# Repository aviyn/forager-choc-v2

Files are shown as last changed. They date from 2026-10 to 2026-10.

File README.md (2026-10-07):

Forager keyboard in white

# Forager

Forager is a Voyager-inspired 34-key low-profile wireless split keyboard powered by ZMK.

> why does the large Voyager not simply eat the small Forager?

## Choc v2 / 19 mm fork

This fork of [carrefinho/forager](https://github.com/carrefinho/forager) reworks the PCB for **Choc v2 hotswap switches at 19 × 19 mm spacing** (each half is about 8 mm wider and 6 mm taller) and adds, on each half:

- a power switch (Alps SSSS811101)
- an optional reset button (Panasonic EVQ-PUC02K)
- three SK6812MINI-E status LEDs behind a P-FET power switch

The schematic and board are done. The case, the LED firmware, the Gerbers and the build guide have not been updated yet and still describe the original design. See [the full list of changes](/docs/changes.md).

## Design

- Condensed [ZSA Voyager](https://www.zsa.io/voyager) layout without outer pinkie column and number row
- Hot-swap Kailh Choc V1 switches in Choc (18x17mm) spacing with Voyager-esque switch puller grooves

Switch-plate cutouts

- Wireless only with Seeed XIAO nRF52840 running ZMK firmware
- Magnetic tenting legs inspired by Voyager and [Unicorne](https://www.boardsource.xyz/products/unicorne)

Forager keyboard with magnetic tenting legs attached

- Compact silhouette without the usual blank space occupied by controller
- Fully enclosed with 3D-printed two-piece case
- Minimal BOM by utilizing XIAO nRF52840's onboard RGB LED and reset button

Forager keyboard with LED indicator lit up in blue alongside reset button on the bottom

## Build Guide and Parts List

[Find the build guide here.](/docs/build-guide.md)

## Firmware

[Find the ZMK module here.](https://github.com/carrefinho/forager-zmk-module)

## Credits

- [ZSA Voyager](https://www.zsa.io/voyager): overall layout & aesthetics
- [GEIGEIGEIST/TOTEM](https://github.com/GEIGEIGEIST/TOTEM): XIAO PCB footprint and general placement
- [ebastler/marbastlib](https://github.com/ebastler/marbastlib): symbols and PCB footprints
- [caksoylar/zmk-rgbled-widget](https://github.com/caksoylar/zmk-rgbled-widget): RGB LED functionality

## Gallery

Forager keyboard in white
Forager keyboard in black and white
Forager keyboard with detached tenting leg
Forager keyboard in black

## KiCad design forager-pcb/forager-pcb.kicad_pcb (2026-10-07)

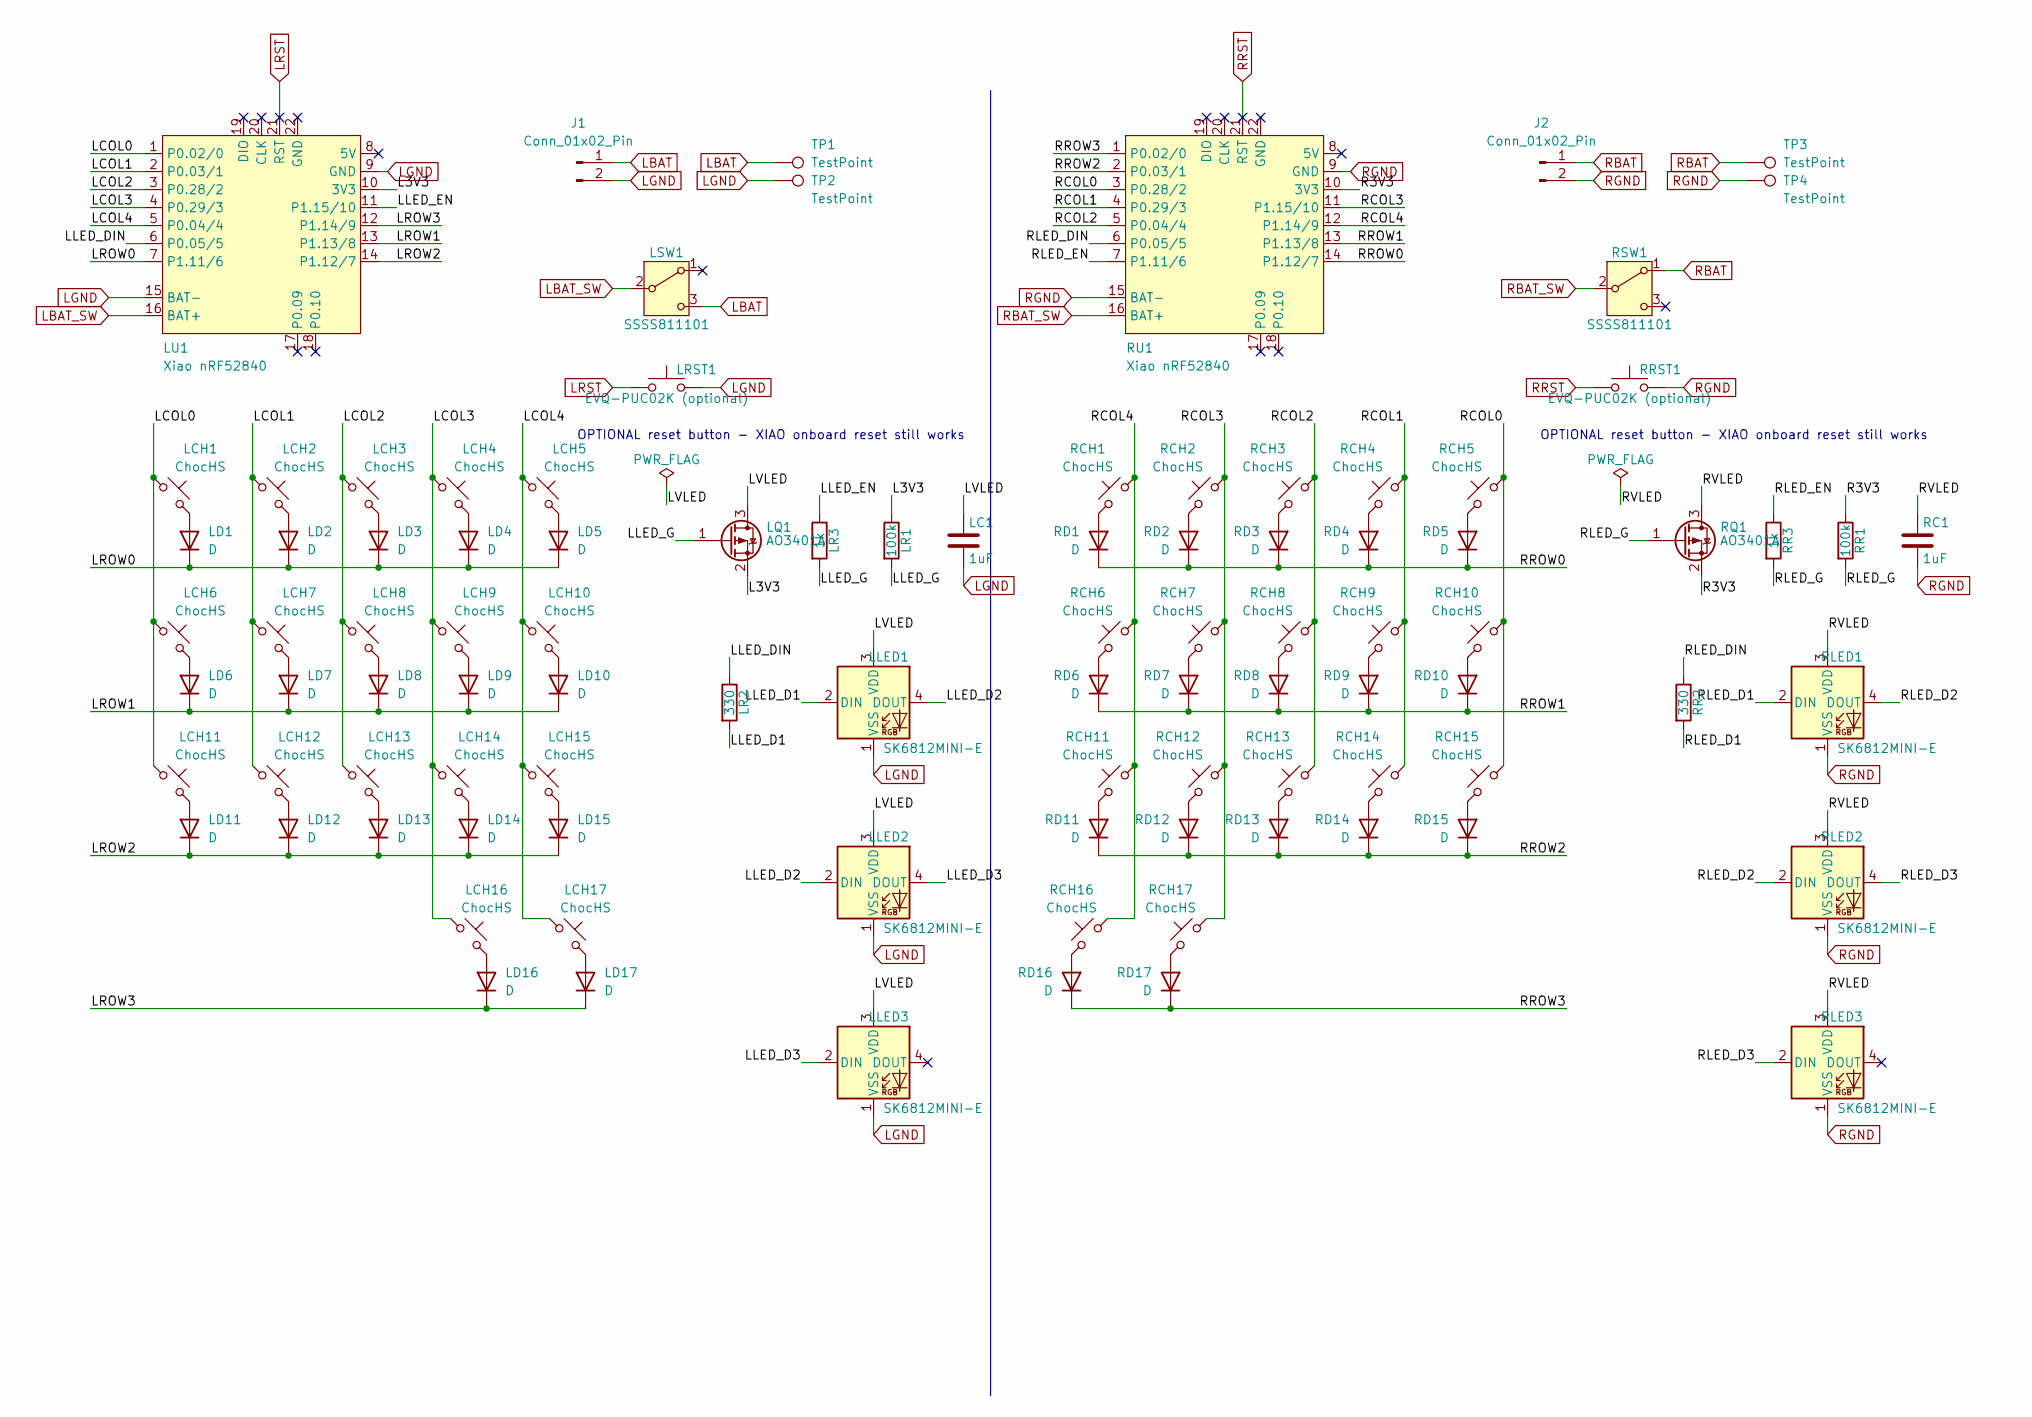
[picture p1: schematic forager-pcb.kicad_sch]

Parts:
J1, J2: Conn_01x02_Pin; JST_ACH_BM02B-ACHSS-GAN-ETF_1x02-1MP_P1.20mm_Vertical
LC1: 1uF; C_1206_3216Metric_Pad1.33x1.80mm_HandSolder; LCSC C1848
LCH1, LCH2, LCH3, LCH4, LCH5, LCH6, LCH7, LCH8, LCH9, LCH10, LCH11, LCH12, LCH13, LCH14, LCH15, LCH16, LCH17: ChocHS; SW_choc_v2_HS_CPG135001S30_1u_nopost
LD1, LD2, LD3, LD4, LD5, LD6, LD7, LD8, LD9, LD10, LD11, LD12, LD13, LD14, LD15, LD16, LD17: D; D_SOD-123
LLED1, LLED2, LLED3: SK6812MINI-E; LED_SK6812MINI-E_3.2x2.8mm_P1.5mm_ReverseMount; LCSC C5149201
LQ1: AO3401A; SOT-23; LCSC C347476
LR1: 100k; R_1206_3216Metric_Pad1.30x1.75mm_HandSolder; LCSC C17900
LR2: 330; R_1206_3216Metric_Pad1.30x1.75mm_HandSolder; LCSC C25374
LR3: 1k; R_1206_3216Metric_Pad1.30x1.75mm_HandSolder; LCSC C4410
LRST1: EVQ-PUC02K (optional); SW_Panasonic_EVQPUC02K
LSW1: SSSS811101; SW_SPDT_Alps_SSSS811101
LU1: Xiao nRF52840; xiao-ble-smd-cutout
RC1: 1uF; C_1206_3216Metric_Pad1.33x1.80mm_HandSolder; LCSC C1848
RCH1, RCH2, RCH3, RCH4, RCH5, RCH6, RCH7, RCH8, RCH9, RCH10, RCH11, RCH12, RCH13, RCH14, RCH15, RCH16, RCH17: ChocHS; SW_choc_v2_HS_CPG135001S30_1u_nopost
RD1, RD2, RD3, RD4, RD5, RD6, RD7, RD8, RD9, RD10, RD11, RD12, RD13, RD14, RD15, RD16, RD17: D; D_SOD-123
RLED1, RLED2, RLED3: SK6812MINI-E; LED_SK6812MINI-E_3.2x2.8mm_P1.5mm_ReverseMount; LCSC C5149201
RQ1: AO3401A; SOT-23; LCSC C347476
RR1: 100k; R_1206_3216Metric_Pad1.30x1.75mm_HandSolder; LCSC C17900
RR2: 330; R_1206_3216Metric_Pad1.30x1.75mm_HandSolder; LCSC C25374
RR3: 1k; R_1206_3216Metric_Pad1.30x1.75mm_HandSolder; LCSC C4410
RRST1: EVQ-PUC02K (optional); SW_Panasonic_EVQPUC02K
RSW1: SSSS811101; SW_SPDT_Alps_SSSS811101
RU1: Xiao nRF52840; xiao-ble-smd-cutout
TP1, TP2, TP3, TP4: TestPoint; TestPoint_Pad_D2.0mm

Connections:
/L3V3: LQ1.2 (S), LR1.1, LU1.10 (3V3)
/LCOL0: LCH1.1, LCH6.1, LCH11.1, LU1.1 (P0.02/0)
/LCOL1: LCH2.1, LCH7.1, LCH12.1, LU1.2 (P0.03/1)
/LCOL2: LCH3.1, LCH8.1, LCH13.1, LU1.3 (P0.28/2)
/LCOL3: LCH4.1, LCH9.1, LCH14.1, LCH16.1, LU1.4 (P0.29/3)
/LCOL4: LCH5.1, LCH10.1, LCH15.1, LCH17.1, LU1.5 (P0.04/4)
/LLED_D1: LLED1.2 (DIN), LR2.2
/LLED_D2: LLED1.4 (DOUT), LLED2.2 (DIN)
/LLED_D3: LLED2.4 (DOUT), LLED3.2 (DIN)
/LLED_DIN: LR2.1, LU1.6 (P0.05/5)
/LLED_EN: LR3.1, LU1.11 (P1.15/10)
/LLED_G: LQ1.1 (G), LR1.2, LR3.2
/LROW0: LD1.1 (K), LD2.1 (K), LD3.1 (K), LD4.1 (K), LD5.1 (K), LU1.7 (P1.11/6)
/LROW1: LD6.1 (K), LD7.1 (K), LD8.1 (K), LD9.1 (K), LD10.1 (K), LU1.13 (P1.13/8)
/LROW2: LD11.1 (K), LD12.1 (K), LD13.1 (K), LD14.1 (K), LD15.1 (K), LU1.14 (P1.12/7)
/LROW3: LD16.1 (K), LD17.1 (K), LU1.12 (P1.14/9)
/LVLED: LC1.1, LLED1.3 (VDD), LLED2.3 (VDD), LLED3.3 (VDD), LQ1.3 (D)
/R3V3: RQ1.2 (S), RR1.1, RU1.10 (3V3)
/RCOL0: RCH5.1, RCH10.1, RCH15.1, RU1.3 (P0.28/2)
/RCOL1: RCH4.1, RCH9.1, RCH14.1, RU1.4 (P0.29/3)
/RCOL2: RCH3.1, RCH8.1, RCH13.1, RU1.5 (P0.04/4)
/RCOL3: RCH2.1, RCH7.1, RCH12.1, RCH17.1, RU1.11 (P1.15/10)
/RCOL4: RCH1.1, RCH6.1, RCH11.1, RCH16.1, RU1.12 (P1.14/9)
/RLED_D1: RLED1.2 (DIN), RR2.2
/RLED_D2: RLED1.4 (DOUT), RLED2.2 (DIN)
/RLED_D3: RLED2.4 (DOUT), RLED3.2 (DIN)
/RLED_DIN: RR2.1, RU1.6 (P0.05/5)
/RLED_EN: RR3.1, RU1.7 (P1.11/6)
/RLED_G: RQ1.1 (G), RR1.2, RR3.2
/RROW0: RD1.1 (K), RD2.1 (K), RD3.1 (K), RD4.1 (K), RD5.1 (K), RU1.14 (P1.12/7)
/RROW1: RD6.1 (K), RD7.1 (K), RD8.1 (K), RD9.1 (K), RD10.1 (K), RU1.13 (P1.13/8)
/RROW2: RD11.1 (K), RD12.1 (K), RD13.1 (K), RD14.1 (K), RD15.1 (K), RU1.2 (P0.03/1)
/RROW3: RD16.1 (K), RD17.1 (K), RU1.1 (P0.02/0)
/RVLED: RC1.1, RLED1.3 (VDD), RLED2.3 (VDD), RLED3.3 (VDD), RQ1.3 (D)
LBAT: J1.1, LSW1.3 (C), TP1.1 (1_1)
LBAT_SW: LSW1.2 (B), LU1.16 (BAT+)
LGND: J1.2, LC1.2, LLED1.1 (VSS), LLED2.1 (VSS), LLED3.1 (VSS), LRST1.2, LU1.9 (GND), LU1.15 (BAT-), TP2.1 (1_1)
LRST: LRST1.1, LU1.21 (RST)
unnamed: LCH1.2, LD1.2 (A)
unnamed: LCH2.2, LD2.2 (A)
unnamed: LCH3.2, LD3.2 (A)
unnamed: LCH4.2, LD4.2 (A)
unnamed: LCH5.2, LD5.2 (A)
unnamed: LCH6.2, LD6.2 (A)
unnamed: LCH7.2, LD7.2 (A)
unnamed: LCH8.2, LD8.2 (A)
unnamed: LCH9.2, LD9.2 (A)
unnamed: LCH10.2, LD10.2 (A)
unnamed: LCH11.2, LD11.2 (A)
unnamed: LCH12.2, LD12.2 (A)
unnamed: LCH13.2, LD13.2 (A)
unnamed: LCH14.2, LD14.2 (A)
unnamed: LCH15.2, LD15.2 (A)
unnamed: LCH16.2, LD16.2 (A)
unnamed: LCH17.2, LD17.2 (A)
unnamed: RCH1.2, RD1.2 (A)
unnamed: RCH2.2, RD2.2 (A)
unnamed: RCH3.2, RD3.2 (A)
unnamed: RCH4.2, RD4.2 (A)
unnamed: RCH5.2, RD5.2 (A)
unnamed: RCH6.2, RD6.2 (A)
unnamed: RCH7.2, RD7.2 (A)
unnamed: RCH8.2, RD8.2 (A)
unnamed: RCH9.2, RD9.2 (A)
unnamed: RCH10.2, RD10.2 (A)
unnamed: RCH11.2, RD11.2 (A)
unnamed: RCH12.2, RD12.2 (A)
unnamed: RCH13.2, RD13.2 (A)
unnamed: RCH14.2, RD14.2 (A)
unnamed: RCH15.2, RD15.2 (A)
unnamed: RCH16.2, RD16.2 (A)
unnamed: RCH17.2, RD17.2 (A)
RBAT: J2.1, RSW1.1 (A), TP3.1 (1_1)
RBAT_SW: RSW1.2 (B), RU1.16 (BAT+)
RGND: J2.2, RC1.2, RLED1.1 (VSS), RLED2.1 (VSS), RLED3.1 (VSS), RRST1.2, RU1.9 (GND), RU1.15 (BAT-), TP4.1 (1_1)
RRST: RRST1.1, RU1.21 (RST)

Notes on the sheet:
OPTIONAL reset button - XIAO onboard reset still works

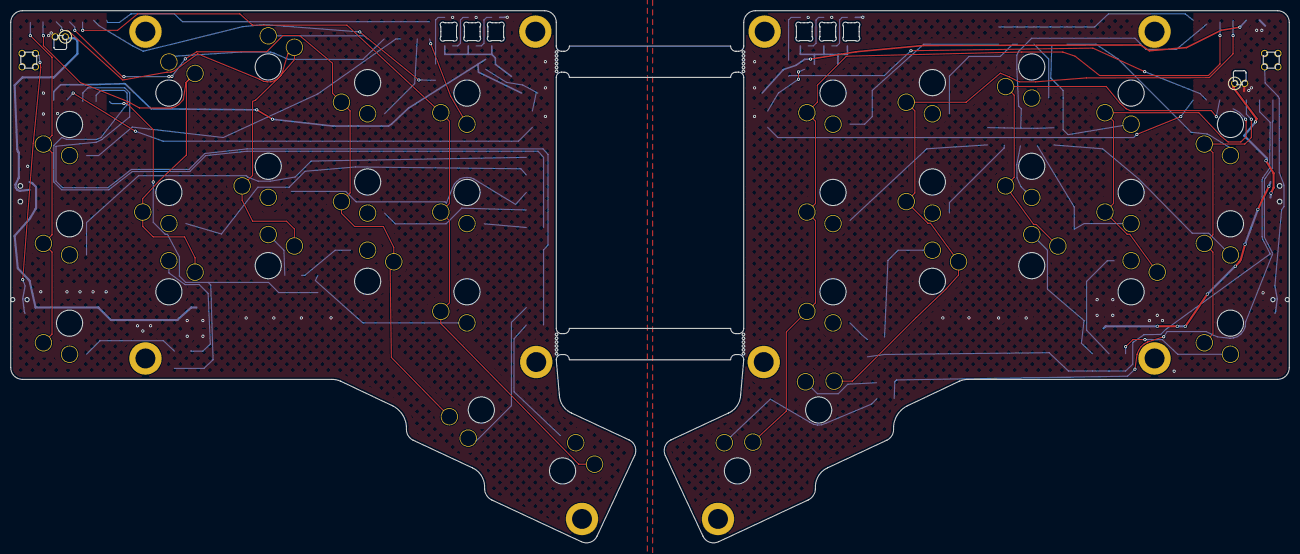
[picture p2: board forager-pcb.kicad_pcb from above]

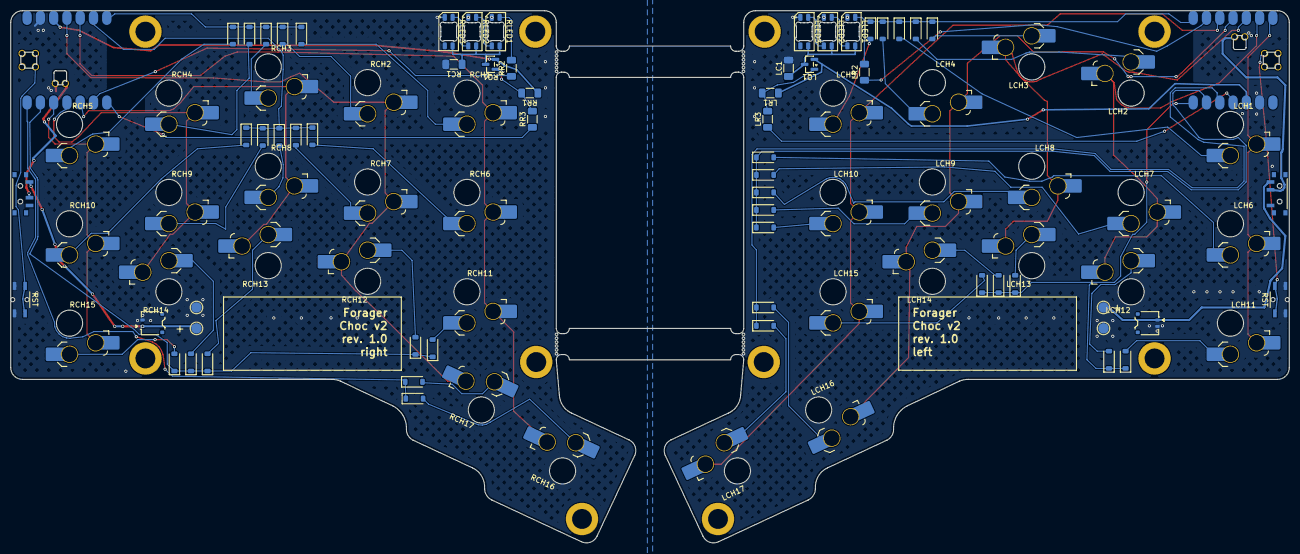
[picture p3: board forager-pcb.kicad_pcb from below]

Board: 2 copper layers, 244.5 x 101.8 mm, 96 parts (96 on the bottom side), 76 nets.

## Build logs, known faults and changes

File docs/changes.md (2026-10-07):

# Forager Choc v2 / 19 mm: Changes

This fork modifies the [original Forager](https://github.com/carrefinho/forager) PCB. It moves the board from **Choc v1 hotswap at 18 × 17 mm** to **Choc v2 hotswap at 19 × 19 mm**, and adds a power switch, an optional reset button and status LEDs to each half.

> **Status:** the schematic and PCB are complete and routed (DRC: 0 errors, 0 unconnected items; ERC: no new errors compared with the original). The [build guide](build-guide.md), the [case](../case/) and the Gerbers still describe the **original** design. See [Not done yet](#not-done-yet).

## Summary

| Area | Original | This fork |
| ---- | --- | --- |
| Switches | Choc v1 hotswap | Choc v2 hotswap (post-less footprint) |
| Key spacing | 18 × 17 mm | 19 × 19 mm |
| Board size (per half) | - | about 8 mm wider and 6 mm taller |
| Power switch | none | Alps SSSS811101 on each half |
| Reset button | XIAO onboard button only | optional Panasonic EVQ-PUC02K on each half |
| Status LEDs | XIAO onboard RGB LED | 3 × SK6812MINI-E per half, behind a P-FET power switch |

## What changed

### 19 × 19 mm grid

- Every key was moved to a 19 × 19 mm pitch. The stagger is kept; only the pitch changed.
- The home row and the inner column stay where they were. Each column moves outward by 1 mm per column, and the top and bottom rows move 2 mm away from the home row.
- Thumb keys keep their 25° angle at the 19 mm pitch, with 1 mm of extra drop to keep the keycap gap.
- Traces, vias, outline, snap-off tabs and GND pours were remapped to match, and the XIAO antenna keepouts moved with the XIAOs.

### Choc v2 hotswap footprint

- Footprint: `forager:SW_choc_v2_HS_CPG135001S30_1u_nopost`, in [`forager-pcb/lib/forager.pretty/`](../forager-pcb/lib/forager.pretty/).
- It is derived from marbastlib's `SW_choc_v2_HS_CPG135001S30_1u`, which is vendored with its license in [`forager-pcb/lib/marbastlib-xp-choc.pretty/`](../forager-pcb/lib/marbastlib-xp-choc.pretty/).
- The centre hole is **5.0 mm**. It was not widened, to avoid switch rattle.
- The footprint has **no side positioning post**, because the post collided with XIAO pins, J1, diodes, test points and a standoff. If your switches have the post, clip it off.
- The socket is still the CPG135001S30, with its pads in the same positions as the v1 footprint.
- Choc v2 has a 5.0 mm centre stem (v1 has 3.4 mm) but the same socket pin positions. Kailh's "Pro" Choc switches (Red, Pink, Light Blue Pro) are still **v1**.

### XIAO

- Both XIAOs moved 0.3 mm toward the top edge so the outer top key's 5 mm hole clears XIAO pins 4 and 11.
- A ground tie trace now connects pad 15 (front) and pad 9 (back) to the GND fill.

### Power switch (both halves)

- Part: **Alps SSSS811101**. The land pattern was checked against the Alps drawing (terminals at -2.25, +0.75 and +2.25 mm, with ② as the common).
- Footprint: `forager:SW_SPDT_Alps_SSSS811101`, on the back side at the outer edge below the XIAO. The slider overhangs the board edge by about 1 mm.
- Circuit: battery (J1/J2 and test pad) → switch → XIAO BAT+. The new nets are `LBAT_SW` and `RBAT_SW`.
- **Slider up = on** on both halves. The down-end pin is not connected.
- Routing changes: the left battery trace was rerouted; on the right, `RROW2` and `RROW3` jog about 1.5 mm inward and the battery traces hop to the front copper. Three GND stitching vias under the left switch were removed.

### Reset button (optional, both halves)

- Part: **Panasonic EVQ-PUC02K**, side-push with bosses, per Panasonic drawing ES103 No. 2.
- Footprint: `forager:SW_Panasonic_EVQPUC02K`, on the back side at the outer edge **below the power switch**, with the push plate about 1 mm past the edge.
- Circuit: XIAO RST (pad 21) to GND, on the new nets `LRST` and `RRST`.
- It is optional. The XIAO's onboard reset button still works if you leave it off. Each button has an "RST" silkscreen label.

### Status LEDs (both halves)

- 3 × **SK6812MINI-E** per half, reverse-mounted on the top inner edge and shining up through board cutouts. LED pitch is 4.5 mm.
- Data: XIAO **P0.05** → 330 Ω → LED1 → LED2 → LED3. LED3's DOUT is not connected.
- Power: an **AO3401A** P-FET switches the LED supply from the XIAO's 3V3 pin, so the LEDs draw nothing when off. The enable line is active low, with a 1k series resistor and a 100k pull-up, plus a 1 µF capacitor on the switched rail.
- **This uses every remaining free GPIO on both XIAOs.**

| Signal | Left half | Right half |
| --- | --- | --- |
| LED data (DIN) | P0.05 (pad 6) | P0.05 (pad 6) |
| LED enable (active low) | P1.15 (pad 11) | P1.11 (pad 7) |
| LED supply | 3V3 (pad 10) | 3V3 (pad 10) |

- **LED order:** the chain runs left to right (+x) on both halves. On the left half LED1 is the outer LED (nearest the XIAO); on the right half LED1 is the inner LED. Firmware has to map the indices accordingly.
- **Light pipes:** the case needs one 1.75 mm hole centred on each LED, at the six (x, -47.75) positions. Check these against the top-case key openings.
- **Soldering:** four LED ground pads use a via in the pad. Some solder wicks into the open hole, so use a little more solder, or order filled or capped vias.
- Per-LED 100 nF decoupling capacitors were left out.

## Added parts (per half)

| Part | Value / part number | Ref (L / R) | Count | LCSC |
| ---- | --- | --- | ----- | ---- |
| Power switch | Alps SSSS811101 | LSW1 / RSW1 | 1 | - |
| Reset button (optional) | Panasonic EVQ-PUC02K | - | 1 | - |
| RGB LED | SK6812MINI-E | LLED1-3 / RLED1-3 | 3 | C5149201 |
| P-FET | AO3401A (SOT-23) | LQ1 / RQ1 | 1 | C347476 |
| Resistor, 1206 | 100k | LR1 / RR1 | 1 | C17900 |
| Resistor, 1206 | 330 Ω | LR2 / RR2 | 1 | C25374 |
| Resistor, 1206 | 1k | LR3 / RR3 | 1 | C4410 |
| Capacitor, 1206 | 1 µF | LC1 / RC1 | 1 | C1848 |

Multiply by two for a full keyboard. The switches themselves are not in the build guide's parts list, but they now need to be **Choc v2 switches** (for example Kailh Black Cloud) with **MX-compatible keycaps**. The hotswap socket (CPG135001S30) is unchanged.

## Not done yet

- **Case:** the files in [`case/`](../case/) are still for 18 × 17 mm and Choc v1. They need the 19 × 19 outline, Choc v2 plate cutouts (MX-style 14 mm; rethink the puller grooves), moved standoffs, outer-wall slots for the power slider and reset button, six light-pipe holes, and moved XIAO and USB-C openings.
- **Firmware:** the key matrix is unchanged. The LED support still has to be written (a ZMK module with a WS2812 driver on P0.05 via SPI, and the active-low enable GPIO).
- **Fab outputs:** `forager-pcb/GERBER-forager-pcb.zip` is **stale** and still the original board. Regenerate Gerbers, drill, BOM and position files, and check that the LED cutouts appear in Edge.Cuts and that the plotted silkscreen font (Geist) is right.
- **Build guide:** still describes the original build, including the case steps and the onboard-LED light guides.

## Known issues and review items

- Silkscreen: the LED reference labels overlap the LED cutouts. Optionally add an "ON ▲" mark next to the power switches.
- Worth a visual check in KiCad: the `RBAT_SW` reroute on the right half, the `RROW2`/`RROW3` jog around the right power switch, `R3V3` running between the right resistor's pads, and the two-via hop on `RLED_G`.
- Remaining DRC warnings (about 40) are inherited or cosmetic: missing library paths, `lib_footprint_mismatch`, silkscreen overlaps, and schematic-parity items for board-only parts (standoff nuts, snap-off tabs, J1/J2 mounting pads). `copper_edge_clearance` is ignored in this project, as in the original.
- Several footprints (standoffs, switch holes, the XIAO) have no courtyard, so fit checks have to use pads and holes.

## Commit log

2026-10-06 Re-grid Forager to 19x19 mm pitch; add Choc v2 hotswap footprint lib
    Keys moved to 19x19 pitch (column stagger and thumb angle kept), traces,
    vias, outline, zones remapped. Schematic switch footprints set to
    marbastlib-xp-choc:SW_choc_v2_HS_CPG135001S30_1u.
    [forager-pcb.kicad_pcb, forager-pcb.kicad_sch]
2026-10-06 Use post-less Choc v2 hotswap footprint (5.0mm centre stem) for all switches
    New project lib forager.pretty with SW_choc_v2_HS_CPG135001S30_1u_nopost,
    derived from marbastlib (side positioning post removed).
    [forager-pcb.kicad_pcb, forager-pcb.kicad_sch]
2026-10-06 Reroute traces around Choc v2 5mm centre holes
    45 trace chains locally rerouted (6 hop layers via 2 vias each), 3 GND
    vias nudged, near-miss clearances fixed. DRC: 0 unconnected; remaining
    errors are 2 XIAO pin-to-centre-hole and 5 XIAO GND thermal spokes.
    [forager-pcb.kicad_pcb]
2026-10-06 Move XIAOs 0.3mm up for centre-hole clearance; tie XIAO GND pads to fill
    DRC: 0 errors, 0 unconnected.
    [forager-pcb.kicad_pcb]
2026-10-06 Add 3D models: Choc switch, hotswap socket, MX keycap, XIAO (vendored)
    Choc v1 switch model used as visual stand-in for Choc v2 (same housing).
    [forager-pcb.kicad_pcb]
2026-10-06 Fix XIAO 3D model orientation (USB-C out the side edge)
    [forager-pcb.kicad_pcb]
2026-10-06 Silkscreen: Forager / Choc v2 / rev. 1.0
    [forager-pcb.kicad_pcb]
2026-10-06 Add Alps SSSS811101 power switches (up = on) on outer edges
    - New footprint forager:SW_SPDT_Alps_SSSS811101 (Alps land pattern) + simple 3D model
    - Schematic: LSW1/RSW1 in series with battery; XIAO BAT+ on new LBAT_SW/RBAT_SW nets
    (POWER class). Battery on the top pin of each switch, so slider up = on on both halves.
    - PCB: switches on bottom at outer edge below XIAO, slider overhanging edge;
    battery lines rerouted, RROW2/RROW3 moved inward around RSW1, 3 GND vias removed.
    - DRC: 0 errors, 0 unconnected.
    [forager-pcb.kicad_pcb, forager-pcb.kicad_sch]
2026-10-06 Add optional Panasonic EVQ-PUC02K reset buttons on outer edges
    - New footprint forager:SW_Panasonic_EVQPUC02K (Panasonic land pattern, with boss) + simple 3D model
    - Schematic: LRST1/RRST1 between XIAO RST (pin 21) and GND; marked optional
    (XIAO onboard reset still works)
    - PCB: bottom side, outer edge below the power switch, push plate ~1 mm past edge;
    RST routed from XIAO, left battery trace rerouted, RGND fill stitched, RST silkscreen
    - DRC: 0 errors, 0 unconnected; ERC unchanged from original
    [forager-pcb.kicad_pcb, forager-pcb.kicad_sch]
2026-10-07 Add 3x SK6812MINI-E status LEDs per half on the top inner edge
    - Reverse-mount LEDs at 4.5 mm pitch near the inner standoff, chained
    from XIAO P0.05 via 330R; P-FET (AO3401A) high-side switch on 3V3,
    enabled active-low from P1.15 (left) / P1.11 (right), 100k gate
    pull-up, 1k gate resistor, 1uF bulk cap. 1206 hand-solder passives.
    - Via-in-pad GND on the boxed-in LED VSS pads; B.Cu rule areas keep
    the back fill out of the LED pad row (fixes copper slivers).
    - Re-route right RBAT_SW on F.Cu, move LD5 and re-route its anode,
    remove XIAO 3V3 no-connect flags.
    - docs/led-indicators-handoff.md documents the design and open items.
    DRC: 0 errors, 0 unconnected. ERC unchanged from baseline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
    [forager-pcb.kicad_pcb, forager-pcb.kicad_sch]
2026-10-07 Update gerber export and KiCad project local settings
2026-10-07 Untrack LED handoff doc (kept locally)
2026-10-07 Add changes doc and README summary for Choc v2 / 19 mm rework
    Document the move to Choc v2 hotswap at 19x19 mm, plus the new power
    switch, optional reset button and status LEDs. Add a short summary to
    the README linking to docs/changes.md.
    Claude-Session: https://claude.ai/code/session_01CdVb7HYwzTa9dDBJmyYMTd
2026-10-11 Use Choc v2 and XIAO nRF52840 3D models on the PCB
    Swap the switch model from Choc v1 to Choc v2, drop the MX keycap
    model, and use the XIAO nRF52840 v3 STEP for both controllers.
2026-10-11 Add left-half Choc v2 case exports and renders
    STEP and STL for the case base, top plate, 12-degree magnetic stand and
    power slider cap, plus the board STEP/DXF exports and edge-control
    reference used to build them. Add assembled, exploded and side renders
    and describe the new case in the README.
2026-10-11 Add LED close-up renders and keycap-less render to README
2026-10-11 Use a higher front-angle LED close-up render
    Keep the back-corner view as forager_left_leds_closeup_back.png.
2026-10-11 README: describe the status LEDs under the close-up render
2026-10-11 Docs: Gerbers are current for the Choc v2 board
    The committed GERBER-forager-pcb.zip was exported after the last
    electrical change (status LEDs); later board edits only touched 3D
    models. Update the README and changes doc accordingly.
2026-10-11 Docs: right half is printed by mirroring the left-half files
2026-10-11 Docs: move case notes out of Not done yet; filament light pipes
    Add a Case section to the changes doc covering the mirrored right half,
    print orientation and light pipes cut from translucent 1.75 mm filament.
2026-10-11 README: warn that the fork is untested and PCBs are just ordered
    Claude-Session: https://claude.ai/code/session_01VxhUF4Mq9d9XUXg3TCxnyt
